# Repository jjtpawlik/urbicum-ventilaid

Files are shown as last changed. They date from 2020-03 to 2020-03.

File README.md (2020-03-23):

# VentilAid

VentilAid - open source ventilator, that can be made anywhere locally
Files names are in Polish - we will fix it and change to English untill 24-25th of March 2020. 

The parts required to assemble the VentilAid are divided into two groups:
1) Printable parts
2) Parts that are mass-produced worldwide

As for the first group, the instructions are the following:
- Print the bellow out of elastic material, for instance TPU. For best results please use material of hardness 80 in Shore A scale. When slicing, the best settings appear to be 1 loop with 0.6-0.7 extrusion width. Apply "Vase mode" whenever it is possible.

- Other 3D printed parts should be sliced with following settings: 2 loops, approx. 15% infill density, layer height from 0.2 mm to 0.5 mm.

The second group contains parts, which are ought to be purchased from local supplier. The list is available below:
- Double acting pneumatic actuator with 16 mm piston and 100-200 mm stroke (the stroke length is responsible for "breath" capacity)
- 12 V solenoid oneumatic valve with adjustable air outlet (mono- or bistable)
- 12 V DC power supply - almost any kind will work
- Standarized pneumatic pressure regulator with approx. 2 bar on the output.
- Source of pneumatic pressure - Ventilaid should work even on compressors for hobbyists

The check-valve and the pressure controller require a soft, elastic discs with hardness of approx. 40 Shore A (or less) and maximal thickness of 1mm - if the supply is low one can make on out of old bike tire tube.

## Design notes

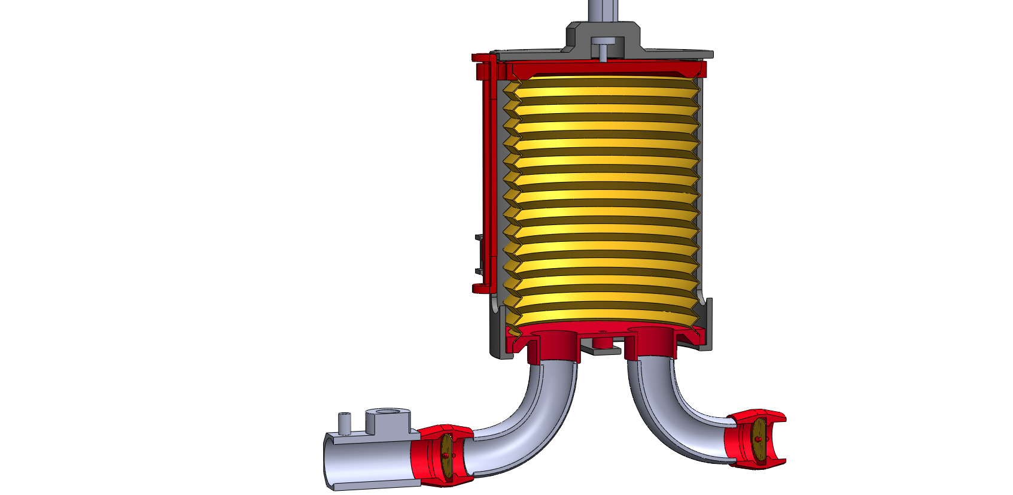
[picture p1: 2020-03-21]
CAD Project/respi1.JPG

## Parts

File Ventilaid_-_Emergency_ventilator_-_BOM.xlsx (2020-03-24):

 | Venti lab
Sl. No | Item | Item Type | Qty
1 | Bellow_soft_filament | 3D Printed - TPU | 1 | For best results please use material of hardness 80 in Shore A scale. When slicing, the best settings appear to be 1 loop with 0.6-0.7 extrusion width. Apply "Vase mode" whenever it is possible.
2 | Chassis_PLA | 3D Printed - PLA | 1 | 3D printed parts should be sliced with following settings: 2 loops, approx. 15% infill density, layer height from 0.2 mm to 0.5 mm.
3 | BellowPiston_PLA 1 | 3D Printed - PLA | 1
4 | ChassisUpperLid_PLA 1 | 3D Printed - PLA | 1
5 | BellowBottomCap_PLA 1 | 3D Printed - PLA | 1
6 | BellowSlideGuard_PLA 1 | 3D Printed - PLA | 1
7 | CheckValve1 | 3D Printed - PLA | 2
8 | CheckValveDisc_elastic | Cut with enclosed punch | 2
9 | pipe90_PLA | 3D Printed -PLA | 2 | Can be purchased separately
10 | Pneumatic Cylinder_supplier | Purchase | 1 | Double acting pneumatic actuator with 16 mm piston and 100-200 mm stroke
11 | Pneumatic Cylinder Piston | Purchase | 1 | 12 V solenoid Pneumatic valve with adjustable air outlet (mono- or bistable
12 | endstop_supplier | Purchase | 1 | To act as electric stoppers
13 | 12 V DC Power Supply | Purchase | 1
14 | Compressor | Purchase | 1 | Baby compressor.. 12 V car tyre compressor
15 | Pneumatic pressure regulator with gauge | Purchase | 1 | Standarized pneumatic pressure regulator with approx. 2 bar on the output.
16
 |  |  | https://www.amazon.in/Generic-Stroke-Pneumatic-Cylinder-MAL16x100/dp/B00VFYCOQ8
 |  |  | https://hpcontrol.pl/tlumik-halasu-regulator-spustu-powietrza-1-8-besld.html
 |  |  | https://hpcontrol.pl/silownik-pneumatyczny-naped-16x150-mal-iso-6432.html
 |  |  | https://hpcontrol.pl/elektrozawor-silownikow-5-2-4v210-1-4-230v-12v-24v.html

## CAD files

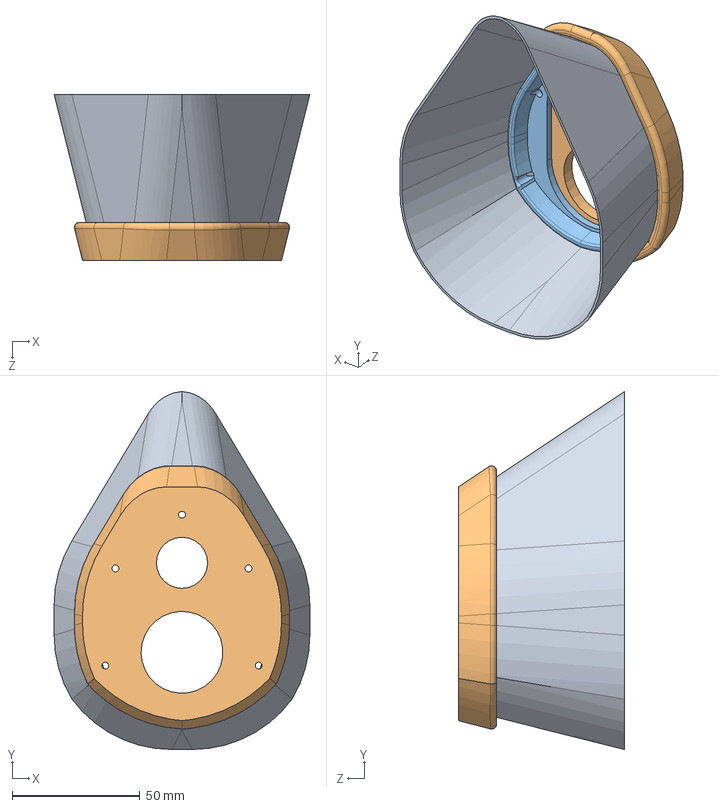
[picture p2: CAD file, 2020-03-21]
CAD Project/mask/maska asse.SLDASM
100.0 x 140.0 x 65.0 mm
maska tpu
maska tpu wyprowadzenie rurek
maska tpu wyprowadzenie rurek docisk

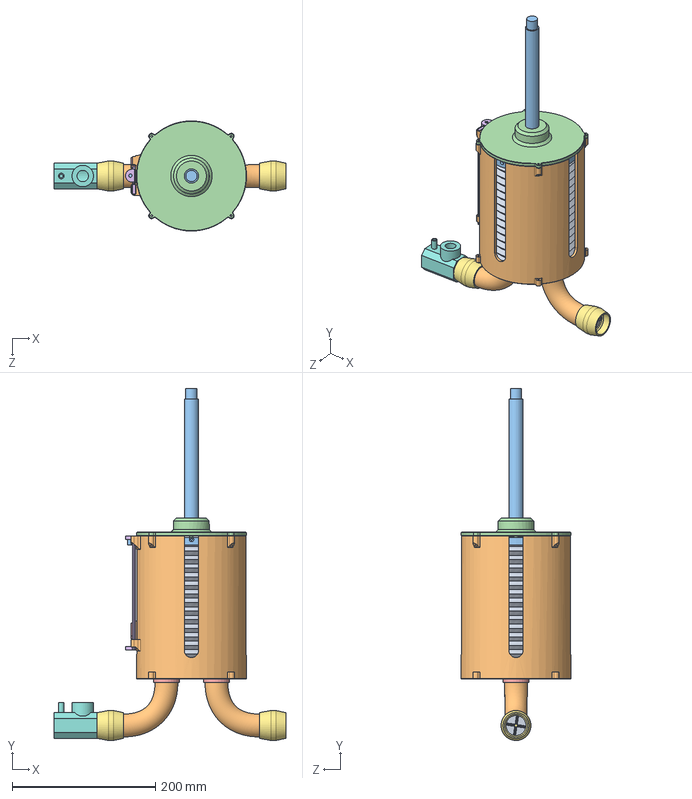
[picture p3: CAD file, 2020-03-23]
CAD Project/CAD Files - Solidworks/VentilAidAssembly.SLDASM
324.0 x 492.3 x 154.0 mm
Bellow_soft_filament
Chassis_PLA
BellowPiston_PLA
ChassisUpperLid_PLA
BellowBottomCap_PLA
BellowSlideGuard_PLA
CheckValve1 x 2
trojnik zbiornik cisnienia
CheckValveDisc_elastic x 2
pipe90_PLA x 2
PneumaticCylinder_supplier
PneumaticCylinderPiston_supplier
endstop_supplier

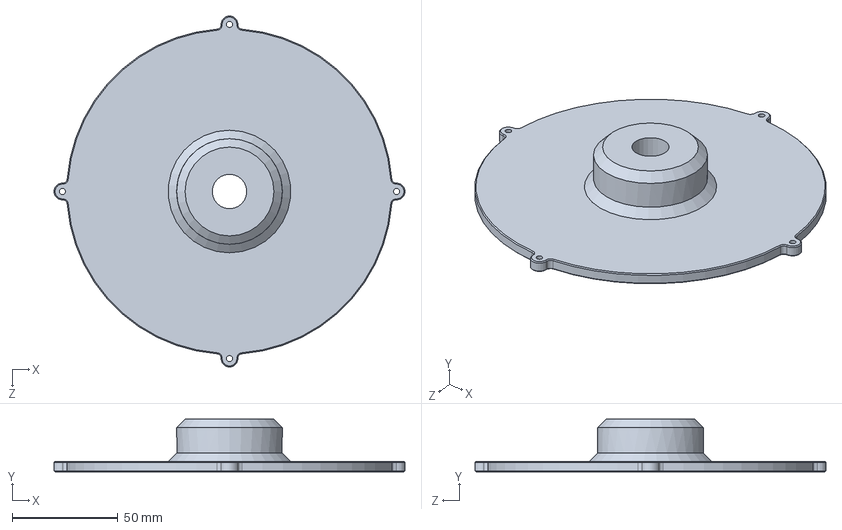
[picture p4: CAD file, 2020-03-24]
CAD Project/CAD Files - Solidworks/ChassisUpperLid_PLA.SLDPRT
166.0 x 25.0 x 166.0 mm

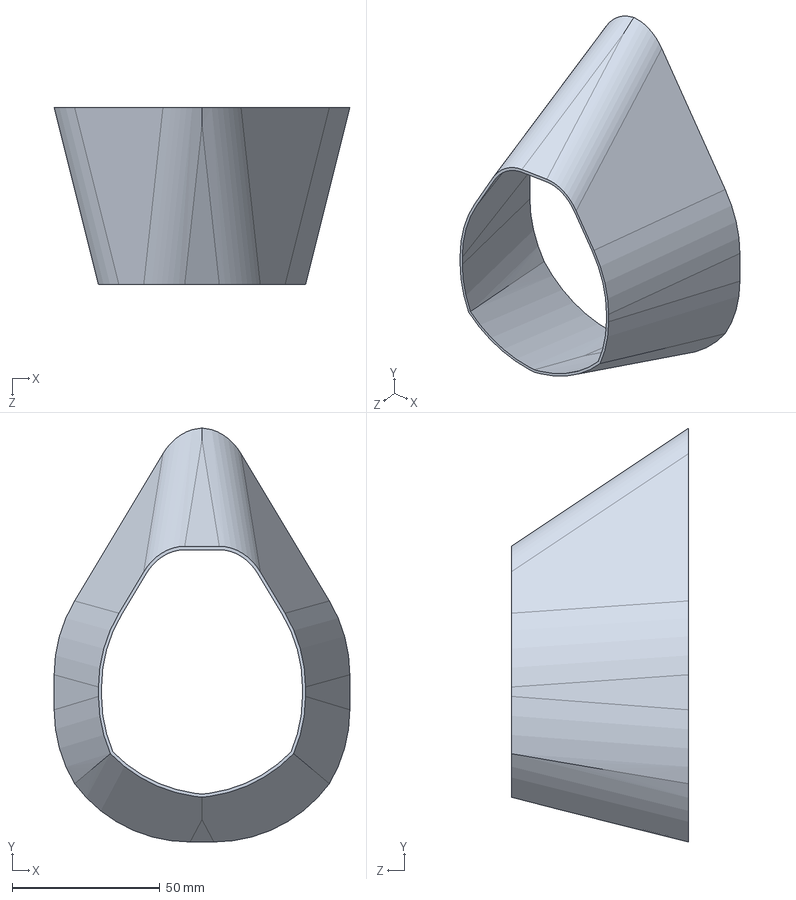
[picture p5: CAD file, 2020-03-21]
CAD Project/mask/maska tpu.SLDPRT
100.0 x 140.0 x 60.0 mm

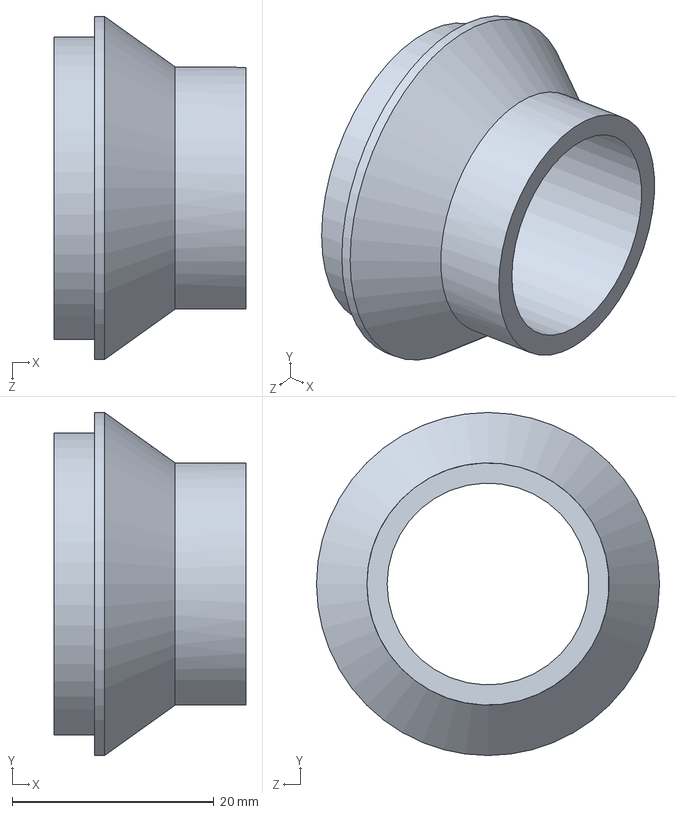
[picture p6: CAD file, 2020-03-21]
CAD Project/misc/zawor jednokierunkowy klapkowy2.SLDPRT
19.0 x 34.0 x 34.0 mm

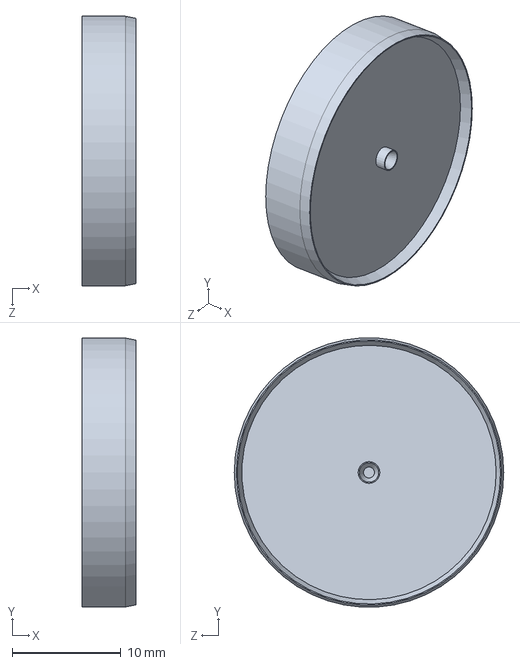
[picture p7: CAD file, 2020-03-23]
CAD Project/CAD Files - Solidworks/CheckValveDiscPunchCutter_PLA.SLDPRT
5.00 x 24.8 x 24.8 mm

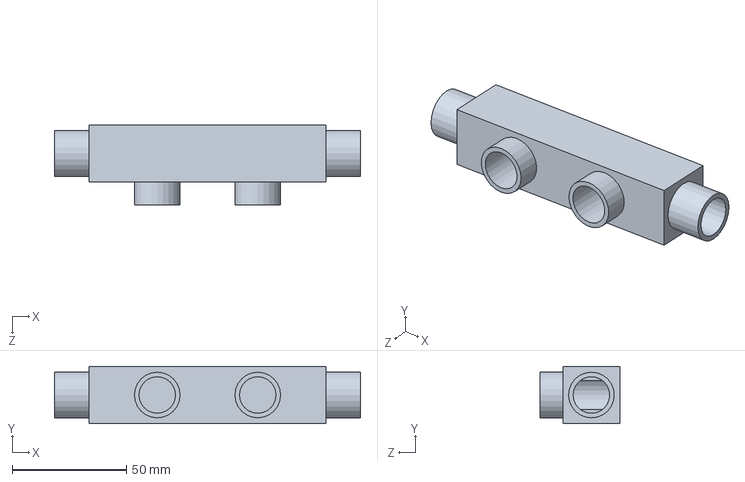
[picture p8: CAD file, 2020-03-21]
CAD Project/misc/rozdzilacz glowny.SLDPRT
134.0 x 25.0 x 35.0 mm

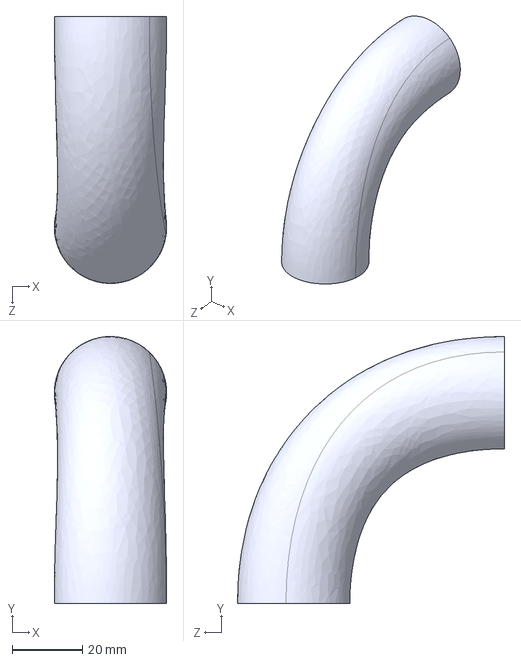
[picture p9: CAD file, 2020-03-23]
STEP files/pipe90_PLA.STEP
32.0 x 76.0 x 76.0 mm

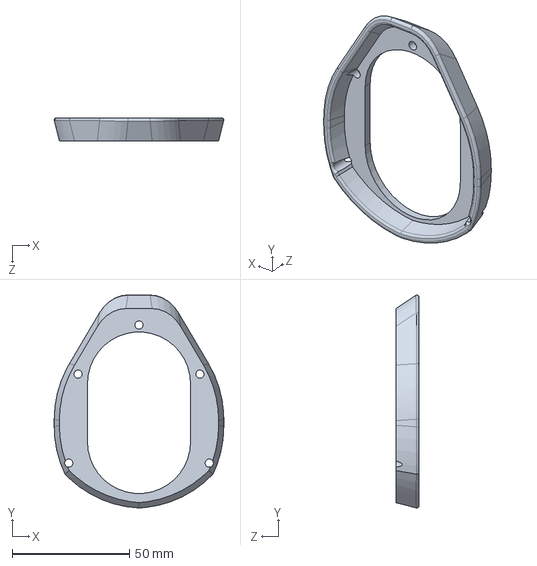
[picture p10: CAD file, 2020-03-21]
CAD Project/mask/maska tpu wyprowadzenie rurek docisk.SLDPRT
72.4 x 91.0 x 10.00 mm

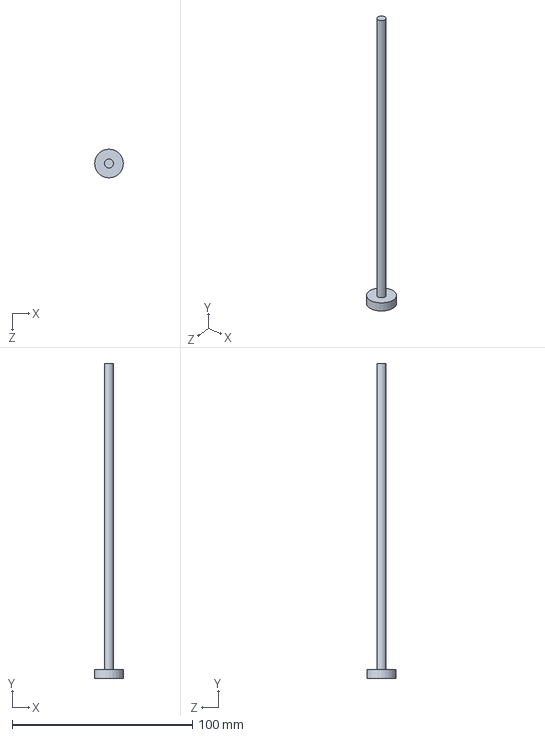
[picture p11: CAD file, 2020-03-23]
CAD Project/CAD Files - Solidworks/PneumaticCylinderPiston_supplier.SLDPRT
16.0 x 175.0 x 16.0 mm

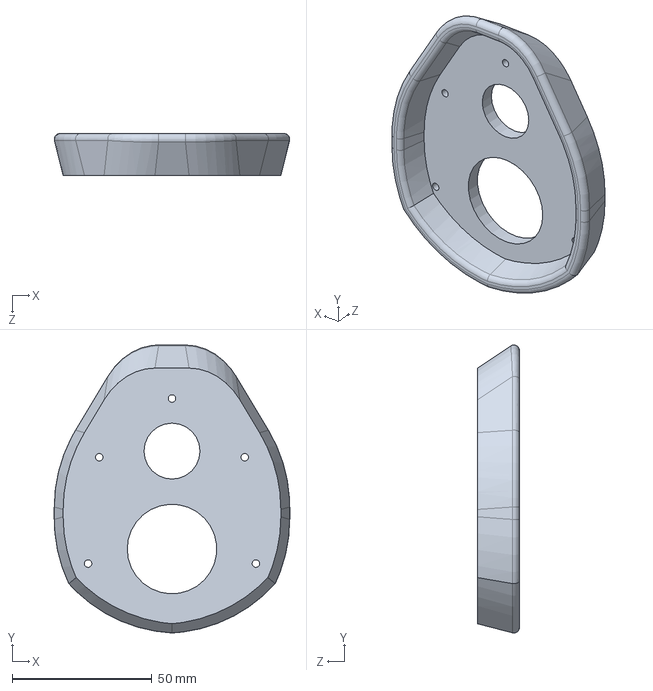
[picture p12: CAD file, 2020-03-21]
CAD Project/mask/maska tpu wyprowadzenie rurek.SLDPRT
84.2 x 102.9 x 15.0 mm

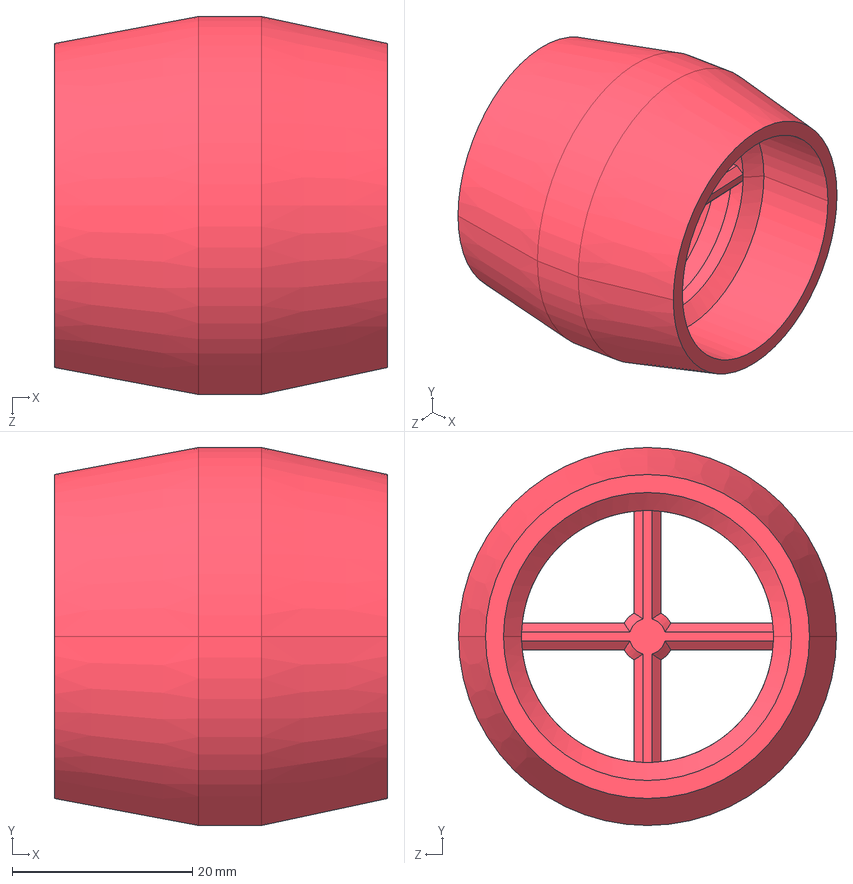
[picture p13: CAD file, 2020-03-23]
STEP files/CheckValve1.STEP
37.0 x 42.0 x 42.0 mm

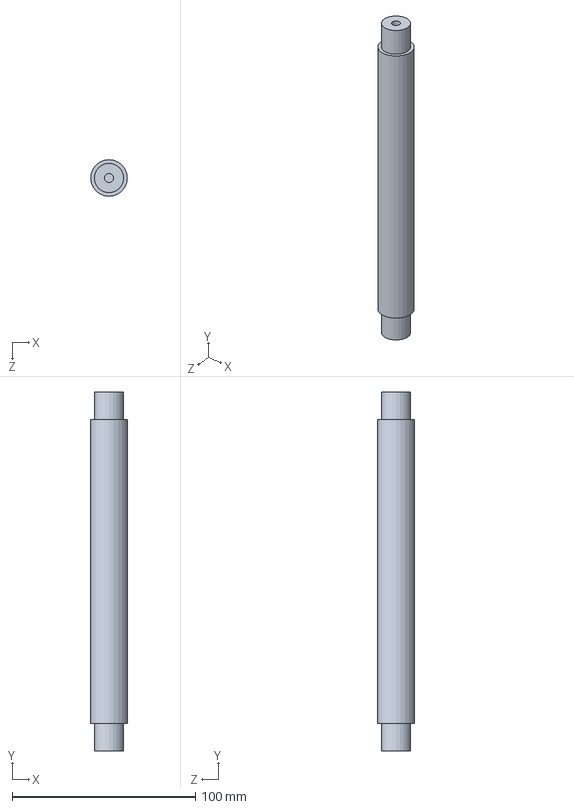
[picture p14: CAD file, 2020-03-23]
CAD Project/CAD Files - Solidworks/PneumaticCylinder_supplier.SLDPRT
20.0 x 196.0 x 20.0 mm

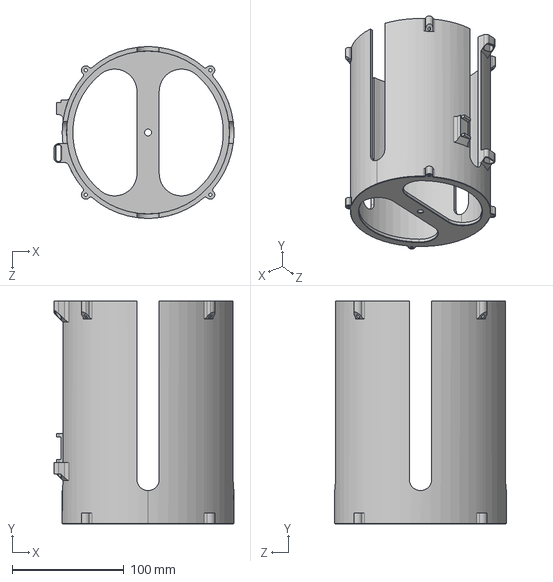
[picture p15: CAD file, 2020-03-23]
STEP files/Chassis_PLA.STEP
161.3 x 200.0 x 154.0 mm

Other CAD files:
CAD Project/respi.STEP
STEP files/ChassisUpperLid_PLA.STEP
STEP files/CheckValveDiscPunchCutter_PLA.STEP
CAD Project/CAD Files - Solidworks/pipe90_PLA.SLDPRT
CAD Project/CAD Files - Solidworks/3WayPneumaticControlValve_supplier.SLDPRT
CAD Project/CAD Files - Solidworks/BellowBottomCap_PLA.SLDPRT
CAD Project/CAD Files - Solidworks/BellowPiston_PLA.SLDPRT
CAD Project/CAD Files - Solidworks/BellowSlideGuard_PLA.SLDPRT
CAD Project/CAD Files - Solidworks/Bellow_soft_filament.SLDPRT
CAD Project/CAD Files - Solidworks/Chassis_PLA.SLDPRT
CAD Project/CAD Files - Solidworks/CheckValve1.SLDPRT
CAD Project/CAD Files - Solidworks/CheckValveDisc_elastic.SLDPRT
CAD Project/CAD Files - Solidworks/endstop_supplier.SLDPRT
STEP files/BellowBottomCap_PLA.STEP
STEP files/BellowPiston_PLA.STEP
STEP files/BellowSlideGuard_PLA.STEP
STEP files/Bellow_soft_filament.STEP

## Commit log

2020-03-21 Add CAD project files
    [cylinder.SLDPRT, endstop.SLDPRT, maska asse.SLDASM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]
2020-03-23 Upload New File
    [3WayPneumaticControlValve_supplier.SLDPRT]
2020-03-24 Replace ChassisUpperLid_PLA.STEP
    [ChassisUpperLid_PLA.STEP]
2020-03-24 Replace ChassisUpperLid_PLA.SLDPRT
    [ChassisUpperLid_PLA.SLDPRT]
2020-03-24 Update CAD Project/mask/maska asse.SLDASM, CAD Project/mask/maska tpu wyprowadzenie rurek docisk.SLDPRT, CAD Project/mask/maska tpu wyprowadzenie rurek.SLDPRT, CAD Project/mask/maska tpu.SLDPRT, Vent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
    [Ventilaid_-_Emergency_ventilator_-_BOM.xlsx, cylinder.SLDPRT, maska asse.SLDASM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]
